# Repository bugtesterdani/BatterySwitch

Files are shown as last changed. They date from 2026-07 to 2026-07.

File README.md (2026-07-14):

# BatterySwitch – Automatischer 2-Akku-Umschalter (58–72 V, 40 A)

Automatische Umschaltung zwischen zwei Akkus (Batterie 1: 50 Ah, Batterie 2: 30 Ah)
in einem **72-V-System** (ca. 71,x V Ladeschluss, ca. 58 V Entladeschluss — z. B.
17s-Li-Ion oder 20s-LiFePO4) durch **direkten Vergleich der beiden Akkuspannungen**
(differentiell, keine feste Umschaltschwelle). Die Umschaltung erfolgt verschleißfrei
über Leistungs-MOSFETs (ausgelegt für ca. 40 A Dauerstrom). Beide Umschalt-Offsets
sind **über je ein Potentiometer getrennt einstellbar**.

## Funktionsprinzip

- Zustand **„Akku 1 aktiv“**: Auf Akku 2 wird umgeschaltet, sobald
  `U(Akku 1) < U(Akku 2) − Δ1` — Δ1 einstellbar mit Poti 1 (ca. 0,4 … 2,9 V).
- Zustand **„Akku 2 aktiv“**: Zurückgeschaltet wird, sobald
  `U(Akku 2) < U(Akku 1) − Δ2` — Δ2 einstellbar mit Poti 2 (unabhängig nachjustierbar).
- Zusätzlich wirkt eine **feste Zusatzhysterese** (ca. 0,1 … 0,8 V je Richtung,
  abhängig von den Poti-Stellungen). Das gesamte Umschaltfenster beträgt damit
  `Δ1 + Δ2` (typisch 2 … 4 V) — die Schaltung schaltet selten, und der
  Stützkondensator am Ausgang wird durch Umschalt-Totzeiten kaum belastet.
- Beim Leerfahren wechseln sich die Akkus automatisch ab und werden gemeinsam
  entladen; wird einer der Akkus geladen, übernimmt er automatisch die Last.

```
 BAT1 (50Ah, 72V) o──[Sicherung 50A/80VDC]──┤ MOSFET-Schalter S1 ├──┐
      │ Sense                                                        ├──o LAST +
 BAT2 (30Ah, 72V) o──[Sicherung 50A/80VDC]──┤ MOSFET-Schalter S2 ├──┘
      │ Sense                                          ▲
      ▼                                                │
  Differenzkomparator (U1 ⇄ U2) ───────────────────────┘
  Δ1-Poti · Δ2-Poti · Photovoltaik-Gate-Treiber · Break-before-make
```

## Eckdaten

| Parameter | Wert |
|---|---|
| Systemspannung | 58 … 72 V DC |
| Dauerstrom | 40 A (Spitze kurzzeitig höher) |
| Schaltelemente | antiserielle N-Kanal-MOSFETs je Zweig (IRF100P219, TO-247, 100 V, ≤ 2 mΩ) |
| Verlustleistung bei 40 A | ca. 7 W je Zweig (1 Paar) bzw. 3,5 W (2 Paare parallel, empfohlen) → Kühlkörper |
| Gate-Ansteuerung | Photovoltaik-Treiber VOM1271 (potentialfrei, inhärent break-before-make) |
| Umschaltkriterium | Differenz U1 − U2 (kein fester Spannungswert) |
| Δ1 (auf Akku 2 schalten) | Poti 1, ca. 0,4 … 2,9 V |
| Δ2 (auf Akku 1 zurück) | Poti 2, ca. 0,4 … 2,9 V |
| Zusatzhysterese (fest) | ca. 0,1 … 0,8 V je Richtung |
| Umschalt-Totzeit | 5 … 10 ms (Akkus werden nie parallel geschaltet) |
| Eigenverbrauch Steuerung | ca. 25 mA (≈ 1,8 W, ≈ 0,6 Ah/Tag) |

## Dokumentation

| Dokument | Inhalt |
|---|---|
| [hardware/BatterySwitch.kicad_sch](hardware/BatterySwitch.kicad_sch) | **KiCad-Schaltplan** (KiCad 6/7/8/9, direkt zu öffnen) — Vorschau: [hardware/preview.svg](hardware/preview.svg) |
| [hardware/BatterySwitch_Steuerplatine.kicad_pcb](hardware/BatterySwitch_Steuerplatine.kicad_pcb) | **Platinenlayout Steuerplatine** (112×92 mm, 2 Lagen, geroutet) — Vorschau: [hardware/preview_pcb.svg](hardware/preview_pcb.svg) |
| [docs/schaltung.md](docs/schaltung.md) | Vollständige Schaltungsbeschreibung, Schaltbilder, Dimensionierung und Formeln |
| [docs/stueckliste.md](docs/stueckliste.md) | Stückliste (BOM) mit Bauteilwerten und Alternativen |
| [docs/bestellliste.md](docs/bestellliste.md) | Bestellliste mit Händlern, Links und ca.-Preisen inkl. MwSt |
| [docs/aufbau-und-abgleich.md](docs/aufbau-und-abgleich.md) | Aufbauhinweise, Verkabelung, Nullabgleich und Einstellen von Δ1/Δ2 |

## Sicherheitshinweise

- **72 V DC ist keine Schutzkleinspannung.** Berührungsschutz vorsehen, nicht
  unter Spannung arbeiten, DC-Lichtbögen beim Trennen unter Last beachten.
- **Die Minusleitungen beider Akku-Stecker werden im Umschalter-Kabelbaum mit
  dem Fahrzeug-Minus verbunden** (gemeinsame Masse nur im Kabelbaum – an den
  Akkus wird nichts geändert, Einzelbetrieb ohne Board bleibt möglich).
  Geschaltet wird ausschließlich der Pluspfad (High-Side).
- Jeder Akku-Anschluss wird **direkt an der Anschlussklemme mit 50 A abgesichert** — Sicherungen mit
  **≥ 80 V DC-Zulassung** (z. B. gPV 14×51). Kfz-Sicherungen (MIDI/MEGA/ANL,
  32 V) sind ungeeignet. Die Sense-Leitungen separat mit 100 mA absichern.
- Leitungsquerschnitt für den Lastpfad: mindestens **10 mm²** bei 40 A. Die beiden
  Sense-Abgriffe direkt an den Anschlussklemmen der Akku-Stecker (vor F1/F2),
  jeweils mit 100 mA abgesichert; beide Akkuzuleitungen gleich ausführen.
- Während der Umschaltung ist die Last für 5 … 10 ms stromlos
  (Break-before-make). Motorcontroller mit eigenem Zwischenkreis stört das nicht.
- Die Schaltung vergleicht nur **relativ** — es gibt keinen absoluten
  Tiefentladeschutz. Die BMS der Akkus bleiben die letzte Schutzinstanz
  (siehe „Grenzen“ in der Schaltungsbeschreibung).

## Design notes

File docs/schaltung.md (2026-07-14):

# Schaltungsbeschreibung

**Systemspannung: 58 … 72 V** (Akkus mit ca. 71,x V Ladeschluss- und ca. 58 V
Entladeschlussspannung, z. B. 17s-Li-Ion oder 20s-LiFePO4).

Die Schaltung vergleicht die Spannungen **beider Akkus direkt miteinander**
(differentiell) – es gibt keine feste Umschaltspannung:

- Zustand **„Akku 1 aktiv“**: Umschalten auf Akku 2, sobald `U1 < U2 − Δ1`
- Zustand **„Akku 2 aktiv“**: Zurückschalten auf Akku 1, sobald `U2 < U1 − Δ2`

Δ1 und Δ2 werden mit **zwei getrennten Potis** eingestellt (je ca. 0,4 … 2,9 V).
Konstruktionsbedingt kommt eine **feste Zusatzhysterese** hinzu (ca. 0,1 … 0,8 V je
Richtung, siehe unten), sodass das Umschaltfenster nie kollabiert und die Schaltung
auch bei knapp eingestellten Potis nur selten schaltet.

> **Achtung – 72 V DC:** Spannungen über 60 V DC gelten nicht mehr als
> Schutzkleinspannung. Berührungsschutz vorsehen, isoliertes Werkzeug verwenden,
> niemals unter Spannung arbeiten. DC-Lichtbögen beim Trennen unter Last beachten.

Funktionsblöcke:

1. [Hilfsspannung VCC (12 V) aus 72 V](#1-hilfsspannung-vcc-12-v-aus-72-v)
2. [Messteiler mit Nullabgleich](#2-messteiler-mit-nullabgleich)
3. [Differenzkomparator mit zwei Hysterese-Potis](#3-differenzkomparator-mit-zwei-hysterese-potis)
4. [Gate-Ansteuerung mit Photovoltaik-Treibern](#4-gate-ansteuerung-mit-photovoltaik-treibern)
5. [Leistungsschalter](#5-leistungsschalter)

Bezeichner (R1, Q1, …) sind konsistent mit der [Stückliste](stueckliste.md).

---

## 1. Hilfsspannung VCC (12 V) aus 72 V

Der LM393 (max. 36 V) kann nicht direkt an 72 V betrieben werden. Ein einfacher
Längsregler aus Zener + Hochvolt-NPN erzeugt eine 12-V-Hilfsschiene. Versorgt wird
er über zwei Schottky-Dioden aus **beiden** Akkus (Dioden-OR), damit die Steuerung
weiterläuft, solange mindestens ein Akku Spannung liefert:

```
BAT1+ o────|>|──────┬──────────────────────┬────o  V+ (≈ max(U1,U2) − 0,4 V)
           D1       │                      │
BAT2+ o────|>|──────┤            [R19a 5,6k / 0,5 W]
           D2      ─┴─ C12               [R19b 5,6k / 0,5 W]
                   ─┬─ 100nF/100V          │
                    │                      ├──────B┤ T5 (MJE340, 300 V)
                    │                      │       │E
                    │                     ─┴─      ├────────o  VCC ≈ 12,3 V
                    │                  ZD3 ▲ 13V  ─┴─ C1 100 µF/25 V
                    │                     ─┬─     ─┬─  + C2 100 nF
GND   o─────────────┴──────────────────────┴──────┴─────────o  GND
                     (Minus beider Akku-Stecker im Kabelbaum verbunden)
```

- Zenerstrom: `(V+ − 13 V) / 11,2 kΩ ≈ 4 … 5 mA`
- T5 verheizt `(V+ − 12,3 V) · ILast ≈ 0,6 W` → TO-126 mit kleinem Aufsteckkühlkörper
- Gesamt-Eigenverbrauch der Schaltung (inkl. Messteiler, Status-LED und
  Optokoppler-LED): **ca. 25 mA aus 72 V ≈ 1,8 W** (≈ 0,6 Ah/Tag)

## 2. Messteiler mit Nullabgleich

Beide Akkuspannungen werden mit **identischen Teilern** (÷28) auf das
Eingangsspannungsniveau des Komparators gebracht. Der Sense-Abgriff (über flinke
100-mA-Sicherungen F3/F4 – eine gequetschte Sense-Leitung an 72 V ist sonst ein
Brandrisiko) erfolgt **direkt an der Anschlussklemme des Akku-Steckers im
Umschalter, vor der Hauptsicherung** – an die Batteriepole selbst kommt man bei
Steckakkus nicht heran, und das ist auch nicht nötig: Abfälle *hinter* dem
Abgriff (F1/F2, MOSFETs) gehen nicht in die Messung ein. Nur Akkukabel und
Steckerkontakt *vor* dem Abgriff wirken als kleiner Messfehler (~0,1–0,3 V bei
40 A, nur beim aktiven Akku) – gleiche Richtung wie der Lasteinbruch, also
unkritisch, solange beide Zuleitungen ähnlich ausgeführt sind:

```
BAT1+ (Sense) o──[F3]──[R1a 27k]──[R1b 27k]──┬─────o  Knoten A  (→ IN+)
                                            ─┴─ C3 100 nF
                                            ─┬─
                                             ├──[R2 2,0k]──o GND

BAT2+ (Sense) o──[F4]──[R3a 27k]──[R3b 27k]──┬─────o  Knoten B  (→ IN−)
                                            ─┴─ C4 100 nF
                                            ─┬─
                                             ├──[R4 1,8k]──[RV3 500Ω Trimmer]──o GND
```

- Teilerverhältnis `α = 2k / 56k ≈ 0,0357` → Knotenspannung ≈ 2,1 V (58 V) … 2,55 V (71,4 V);
  Innenwiderstand je Knoten `Rth = 54k ∥ 2k ≈ 1,93 kΩ`.
- Der obere Teilerwiderstand ist **aufgeteilt in 2× 27 kΩ** (Spannungs- und
  Verlustleistungsreserve; ≈ 35 V und 45 mW je Widerstand).
- **RV3 gleicht die Toleranzen der Teiler ab** (Nullabgleich). Bei ÷28-Teilung
  erzeugen schon 1-%-Widerstände bis zu ±1 V scheinbare Differenz auf
  Batterieebene – ohne Abgleich unbrauchbar. Prozedur siehe
  [Aufbau und Abgleich](aufbau-und-abgleich.md). R1–R4 als Metallfilm 1 %
  (besser 0,1 %), beide Teiler thermisch benachbart aufbauen (gleiche Drift).
- C3/C4 filtern Störspitzen. Nicht wesentlich vergrößern (max. ≈ 470 nF), sonst
  wird die Mitkopplung des Komparators zu träge.

## 3. Differenzkomparator mit zwei Hysterese-Potis

Kern der Schaltung ist ein LM393 (Dual-Komparator, Open-Collector), betrieben an
VCC = 12 V. **Komparator U1a** vergleicht Knoten A (Akku 1) mit Knoten B (Akku 2).
**Komparator U1b** arbeitet als Inverter und erzeugt das Gegensignal /OUT.

Die beiden Offsets Δ1 und Δ2 entstehen durch **zustandsabhängige Stromeinspeisung**
in die Messknoten: Poti RV1 speist von OUT in Knoten A, Poti RV2 speist von /OUT in
Knoten B. Es ist immer genau eine der beiden Einspeisungen aktiv (high):

```
                      VCC                           VCC
                        │                             │
                      [R7 3,3k]                     [R8 3,3k]
                        │                             │
 Knoten A o────┬────────┼────► OUT                    ├────► /OUT
               │      │\│      (high = Akku 1 aktiv)  │
               └──────│+ \                          │\│
                      │    ────┬────────────────────│− \
 Knoten B o───┬───────│− /     │                    │    ──────┬──► /OUT
              │       │/ U1a   │      VCC ──[R9 47k]│+ /       │
              │                │            ├───────│/ U1b     │
              │                │   [R10 47k]│ = VCC/2, C11 100n│
              │                │           GND                 │
              │                │                               │
              │                └──[JP1]──[R5 150k]──[RV1 1M]──┐│
 Knoten A o───┼───────────────────────────────────────────────┘│  (Δ1)
              │                                                 │
              └──────[JP2]──[R6 150k]──[RV2 1M]─────────────────┘  (Δ2)
```

*(JP1/JP2 sind Jumper, die nur für den Nullabgleich geöffnet werden.)*

### Funktionsweise

**Zustand „Akku 1 aktiv“ (OUT high, /OUT low):**
RV1 speist Strom von OUT (≈ VCC) in Knoten A → Akku 1 „wirkt“ um Δ1 höher.
Gleichzeitig zieht RV2 den Knoten B leicht Richtung /OUT (= 0 V) → kleiner fester
Zusatz. Der Komparator kippt erst, wenn

```
U1  <  U2 − Δ1        (Umschalten auf Akku 2)
```

**Zustand „Akku 2 aktiv“ (OUT low, /OUT high):**
Jetzt speist RV2 von /OUT in Knoten B → Akku 2 „wirkt“ um Δ2 höher, RV1 zieht
Knoten A leicht herunter. Zurückgeschaltet wird erst, wenn

```
U2  <  U1 − Δ2        (Zurückschalten auf Akku 1)
```

Das gesamte Umschaltfenster beträgt `Δ1 + Δ2` — nach jedem Umschalten muss sich das
Spannungsverhältnis der Akkus um mindestens dieses Fenster ändern, bevor wieder
geschaltet wird.

> **Wichtig bei 40 A:** Ein 72-V-Akku bricht unter 40 A Last je nach
> Innenwiderstand um 1 … 3 V ein. Damit die Schaltung nach dem Umschalten nicht
> sofort zurückpendelt (der entlastete Akku erholt sich, der neue bricht ein),
> muss `Δ1 + Δ2 > 2 × Lasteinbruch` sein. Deshalb reicht der Einstellbereich
> hier bis ca. 3 V je Richtung (Fenster bis ≈ 7 V).

### Dimensionierung

Einspeisung von OUT (High-Pegel ≈ VCC − 1 V ≈ 10,7 V, Knotenspannung ≈ 2,4 V) über
`Rf = R5 + RV-Anteil` in einen Knoten mit `Rth ≈ 1,93 kΩ`:

```
Δ (eigener Anteil)  ≈ (UOUT,high − UKnoten) · Rth / (Rth + Rf) / α
Δ (fester Zusatz)   ≈  UKnoten · Rth / (Rth + Rf,anderes Poti) / α
Δ1_eff = Δ1(RV1, eigener Anteil) + Zusatz(RV2)      (Δ2 analog mit vertauschten Rollen)
```

| Poti-Stellung | Rf | eigener Anteil | fester Zusatz fürs **andere** Δ |
|---|---|---|---|
| 0 Ω | 150 kΩ | ≈ 2,9 V | ≈ 0,84 V |
| 250 kΩ | 400 kΩ | ≈ 1,1 V | ≈ 0,32 V |
| 500 kΩ | 650 kΩ | ≈ 0,69 V | ≈ 0,20 V |
| 1 MΩ | 1,15 MΩ  | ≈ 0,39 V | ≈ 0,11 V |

**Einstellbereich je Richtung: ca. 0,4 … 2,9 V** (plus fester Zusatz).

Zwei bewusste Eigenschaften dieser einfachen Lösung (für den Einsatzzweck
unkritisch, da beide Potis ohnehin empirisch nachjustiert werden):

1. **Leichte gegenseitige Beeinflussung:** Jedes Poti trägt über den festen Zusatz
   ca. 10–25 % zum jeweils *anderen* Δ bei → beim Einstellen wechselseitig
   nachjustieren. Genau dieser Zusatz liefert die gewünschte feste Extra-Hysterese
   („nochmal ~0,5 V obendrauf“), damit nicht zu oft geschaltet wird.
2. **Δ skaliert schwach mit VCC**, die von der Zenerdiode stabilisiert wird –
   Restabhängigkeit von der Batteriespannung < 5 %.

### Inverter U1b

Der zweite LM393-Komparator vergleicht OUT mit VCC/2 (R9/R10 = 47 kΩ, C11 100 nF)
und liefert /OUT mit sauberem Pegel (Pull-up R8). /OUT steuert die Einspeisung von
Δ2, den Gate-Treiber von Schalter 1 und die LED „Akku 2 aktiv“.

### Verhalten beim Einschalten

Liegen beide Akkuspannungen beim Einschalten innerhalb des Fensters
(|U1 − U2| < Δ), ist der Anfangszustand nicht definiert – die Schaltung wählt
einen Akku und bleibt dort stabil. Das ist unkritisch.

## 4. Gate-Ansteuerung mit Photovoltaik-Treibern

Die N-Kanal-MOSFETs schalten high-side: Ihre Gates müssen ca. 8 … 10 V **über der
72-V-Schiene** liegen (≈ 80 V gegen Masse). Statt einer Hochvolt-Ladungspumpe
kommen **Photovoltaik-MOSFET-Treiber (VOM1271)** zum Einsatz: Eine interne
LED beleuchtet einen Fotodioden-Stapel, der potentialfrei ca. 8,4 V direkt
zwischen Gate und Source liefert – egal, auf welchem Potential die Source liegt.

```
                                  ┌────────────────────┐
V+ ──[R17a 3,3k/1W]──[R17b 3,3k/1W]──|>|── LED         │ OC1 (VOM1271)
                                  │   intern           │
             MPSA42 (300 V!)  C┤──┘        + o─────────┼───o Gate1  (Q1/Q2)
/OUT? nein: OUT-Logik s.u.  B─┤ T1                     │
   OUT o──[R11 27k]───────────┤        − o─────────────┼───o Source-Knoten Q1/Q2
                              │E       (integrierte    │
                             GND        Schnellent-    │
                                        ladung)        │
                                  └────────────────────┘
   (identisch: T2 + R12 27k + R18a/b + OC2 → Gate2/Source-Knoten Q3/Q4,
    T2-Basis an /OUT)
```

- **T1 (Basis an OUT)** schaltet OC1 → Akku-1-Zweig, **T2 (Basis an /OUT)**
  schaltet OC2 → Akku-2-Zweig. Es leuchtet immer nur eine Treiber-LED.
- T1/T2 sind **MPSA42 (300 V)**: Im ausgeschalteten Zustand liegt der Kollektor
  über die LED-Vorwiderstände an V+ (72 V) – ein BC547 (45 V) würde sterben.
- LED-Strom: `(V+ − 1,3 V) / 6,6 kΩ ≈ 9 … 11 mA` über den gesamten
  Batteriespannungsbereich.

### Break-before-make – hier gratis

- **Einschalten langsam:** Der Fotodioden-Stapel liefert nur ~10 µA. Mit der
  Gate-Kapazität der MOSFETs (2× ≈ 10 nF) dauert das Aufladen bis zur
  Schwellspannung **5 … 10 ms** – die Umschaltung ist ein sanfter Soft-Start.
- **Ausschalten schnell:** Der VOM1271 enthält eine aktive
  Schnellentladeschaltung, die das Gate in **< 1 ms** entlädt.

Beim Umschalten (beide LEDs wechseln gleichzeitig) ist der alte Zweig also längst
gesperrt, bevor der neue zu leiten beginnt → **die Akkus werden nie parallel
geschaltet** (wichtig, da sie beim Umschalten konstruktionsbedingt Δ Volt
Differenz haben und sonst hohe Ausgleichsströme flössen).

Während der Totzeit (5 … 10 ms) ist die Last stromlos. Der Stützkondensator C8
überbrückt das nur für kleine Steuerlasten – ein Motorcontroller als Hauptlast
hat aber selbst genug Zwischenkreiskapazität und übersteht die Lücke problemlos.
Da das Umschaltfenster Δ1 + Δ2 groß ist, tritt die Totzeit ohnehin nur selten auf.

## 5. Leistungsschalter

### Antiserielle MOSFET-Paare

Jeder Batteriezweig besteht aus **zwei antiseriellen N-Kanal-MOSFETs**
(Source an Source, Gates verbunden). Nur so sperrt der Schalter in **beide**
Richtungen – mit einem einzelnen MOSFET würde dessen Body-Diode die inaktive
Batterie weiter mit der Last (bzw. mit der anderen Batterie) verbinden.

```
                 Q1 (IRF100P219)    Q2 (IRF100P219)
BAT1+ o──[F1]────D─┤├─S────────S─┤├─D──────────────┬─────o LAST+
                     │►(Body)  ◄│                  │
                     └────┬─────┘                  │
              Gate1 ──────┤   ZD1 15 V             │
              (von OC1)   └──▲├── Source-Knoten    │
                                                   │
                 Q3 (IRF100P219)    Q4 (IRF100P219)│
BAT2+ o──[F2]────D─┤├─S────────S─┤├─D──────────────┘
                     │►        ◄│                 ─┴─ C8  2× 470 µF/100 V
                     └────┬─────┘                 ─┬─  (Stützkondensator)
              Gate2 ──────┤   ZD2 15 V             │
              (von OC2)   └──▲├── Source-Knoten   GND
```

- **MOSFET-Anforderungen:** `UDS ≥ 100 V` (71,4 V max. + Reserve für
  Schaltspitzen), `RDS(on) ≤ 3 mΩ`, gut durchgesteuert bei UGS = 8 V
  (der VOM1271 liefert ca. 8,4 V). Referenztyp IRF100P219 (TO-247, 100 V, ≤ 2 mΩ);
  Alternative IPP023N10N5.
- **Verlustleistung bei 40 A:** `P = 40² · 2 · ≈2,2 mΩ ≈ 7 W` je aktivem Zweig
  (bei UGS 8 V etwas über Datenblattwert) → **dringend empfohlen: je Zweig zwei
  Paare parallel** (8 MOSFETs gesamt, je 10 Ω Einzelgate-Widerstand gegen
  Schwingen) → ≈ 3,5 W je Zweig, ca. 0,9 W pro Gehäuse. Kühlkörper ≤ 6 K/W.
- ZD1/ZD2 (15 V, Gate–Source) schützen die Gates vor eingekoppelten Transienten.
- **Verdrahtungsinduktivität klein halten** (kurze, dicke Leitungen): Beim
  Abschalten unter 40 A erzeugt jede µH Leitungsinduktivität Spannungsspitzen,
  die die 100-V-Reserve aufbrauchen. Bei langen Batterieleitungen je Akku einen
  Elko (220 µF/100 V) direkt an den Schalter-Eingang setzen.

### Status-LEDs

Die LEDs hängen an VCC und werden über eigene Transistoren getrieben, damit sie
die Pegel von OUT//OUT (Einspeisequellen für Δ1/Δ2!) nicht verfälschen:

```
VCC ──[R15 2,2k]──|>|──C┤ T3 (BC547)   Basis ← OUT  via R13 330k
      LED1 grün         │E             „Akku 1 aktiv“
                       GND
VCC ──[R16 2,2k]──|>|──C┤ T4 (BC547)   Basis ← /OUT via R14 330k
      LED2 gelb         │E             „Akku 2 aktiv“
                       GND
```

---

## Grenzen und mögliche Erweiterungen

- **Kein absoluter Tiefentladeschutz:** Die Schaltung vergleicht nur *relativ*.
  Beim Leerfahren wechseln sich die Akkus ab („Leapfrog“) und werden gemeinsam
  entladen – gewollt, um beide Kapazitäten zu nutzen. Die **BMS der beiden Akkus
  bleiben die letzte Instanz** gegen Tiefentladung; bei Akkus ohne BMS einen
  externen Low-Voltage-Disconnect hinter den Ausgang schalten.
- **Kein Laderegler:** Die Schaltung verteilt nur die Entladung. Das Laden beider
  Akkus muss separat erfolgen. Wird ein Akku geladen, während der andere entladen
  ist, schaltet die Last automatisch auf den geladenen Akku – gewolltes Verhalten
  des Differenzvergleichs.
- **Verpolschutz:** Nicht enthalten – bei Verpolung eines Akkus leiten die
  Body-Dioden. Sicherungen F1/F2 begrenzen den Schaden; sorgfältig anschließen.
- **Fehlerfall Messteiler:** Reißt ein unterer Teilerwiderstand (R2/R4) ab, liegt
  der volle Akku an einem LM393-Eingang (max. 36 V) – der Komparator stirbt und
  der Zustand ist undefiniert. Wer es robust mag, ergänzt je Knoten eine
  10-V-Zener nach Masse (identisch an beiden Knoten, um die Symmetrie zu wahren).

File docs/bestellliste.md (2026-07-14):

# Bestellliste

> **Stand: Juli 2026.** Die Händler-Shops blockieren automatische Preisabfragen,
> daher sind die Preise **ca.-Angaben inkl. 19 % MwSt** (aus aktuellen
> Katalogpreisen abgeleitet) — beim Klick auf den Link bitte den Tagespreis
> prüfen. Mengen entsprechen der [Stückliste](stueckliste.md) inkl. der
> empfohlenen 8 MOSFETs (2 Paare parallel je Zweig).

## 1. Mouser (mouser.de) — Halbleiter, die Reichelt nicht führt

Mouser zeigt Preise netto an, an der Kasse kommt MwSt dazu. Versand kostenlos ab 50 € netto, sonst ca. 20 € → **zusammen mit den MOSFETs bestellen, dann ist die Grenze erreicht.**

| Pos. | Bauteil | Menge | Link | ca. €/Stk inkl. MwSt | Summe |
|---|---|---|---|---|---|
| Q1–Q8 | IRF100P219 (TO-247, 100 V, ≤ 2 mΩ) | 8 | [mouser.de/c/?q=IRF100P219](https://www.mouser.de/c/?q=IRF100P219) | 4,50 € | 36,00 € |
| OC1, OC2 | VOM1271T (Vishay, SOP-4) | 2 | [mouser.de → VOM1271T](https://www.mouser.de/ProductDetail/Vishay-Semiconductors/VOM1271T) | 2,90 € | 5,80 € |
| – | SOP-4→DIP-Adapterplatinen (bei Lochraster-Aufbau) | 2 | [mouser.de/c/?q=SOP-4+adapter](https://www.mouser.de/c/?q=SOIC-4+adapter) | 1,00 € | 2,00 € |

**Zwischensumme Mouser: ca. 44 €** *(alternativ DigiKey [digikey.de](https://www.digikey.de), gleiche Teile, ähnliche Preise)*

## 2. Reichelt (reichelt.de) — Standard-Bauteile

Links führen auf die Reichelt-Suche mit dem passenden Suchbegriff. Versand ca. 5,95 €.

| Pos. | Bauteil | Menge | Reichelt-Suche | ca. €/Stk inkl. MwSt | Summe |
|---|---|---|---|---|---|
| U1 | LM393 DIP-8 | 1 | [LM 393 DIP](https://www.reichelt.de/index.html?ACTION=446&q=LM%20393%20DIP) | 0,25 € | 0,25 € |
| T1, T2 | MPSA42 (300 V) | 2 | [MPSA 42](https://www.reichelt.de/index.html?ACTION=446&q=MPSA%2042) | 0,12 € | 0,24 € |
| T3, T4 | BC547B | 2 | [BC 547B](https://www.reichelt.de/index.html?ACTION=446&q=BC%20547B) | 0,06 € | 0,12 € |
| T5 | MJE340 (TO-126) | 1 | [MJE 340](https://www.reichelt.de/index.html?ACTION=446&q=MJE%20340) | 0,55 € | 0,55 € |
| D1, D2 | 1N5819 | 2 | [1N 5819](https://www.reichelt.de/index.html?ACTION=446&q=1N%205819) | 0,10 € | 0,20 € |
| ZD1, ZD2 | Zener 15 V 0,5 W (BZX55C15) | 2 | [ZF 15](https://www.reichelt.de/index.html?ACTION=446&q=ZF%2015) | 0,10 € | 0,20 € |
| ZD3 | Zener 13 V 1,3 W (BZX85C13) | 1 | [ZD 13](https://www.reichelt.de/index.html?ACTION=446&q=ZD%2013) | 0,20 € | 0,20 € |
| LED1, LED2 | LED 3 mm grün + gelb | 2 | [LED 3mm](https://www.reichelt.de/index.html?ACTION=446&q=LED%203mm%20gruen) | 0,15 € | 0,30 € |
| R1–R4 | Metallfilm 1 %: 4× 27 kΩ, 1× 2,0 kΩ, 1× 1,8 kΩ | 6 | [METALL 27,0K](https://www.reichelt.de/index.html?ACTION=446&q=METALL%2027%2C0K) usw. | 0,10 € | 0,60 € |
| R5–R16 | Metallfilm: 2× 150 k, 2× 3,3 k, 2× 47 k, 2× 27 k, 2× 330 k, 2× 2,2 k | 12 | [METALL …](https://www.reichelt.de/index.html?ACTION=446&q=METALL%20150K) | 0,10 € | 1,20 € |
| R17, R18 | Metalloxid 3,3 kΩ 1 W (oder 2 W) | 4 | [2W METALL 3,3K](https://www.reichelt.de/index.html?ACTION=446&q=2W%20METALL%203%2C3K) | 0,20 € | 0,80 € |
| R19 | 5,6 kΩ 0,5 W | 2 | [1/2W 5,6K](https://www.reichelt.de/index.html?ACTION=446&q=1%2F2W%205%2C6K) | 0,10 € | 0,20 € |
| Rg | 10 Ω (Einzelgate-Widerstände) | 8 | [METALL 10,0](https://www.reichelt.de/index.html?ACTION=446&q=METALL%2010%2C0) | 0,10 € | 0,80 € |
| RV1, RV2 | Poti 1 MΩ linear, 6-mm-Achse | 2 | [PO4M-LIN 1,0M](https://www.reichelt.de/index.html?ACTION=446&q=PO4M-LIN%201%2C0M) | 1,50 € | 3,00 € |
| RV3 | Spindeltrimmer 500 Ω, 25 Gang | 1 | [64W-500](https://www.reichelt.de/index.html?ACTION=446&q=64W-500) | 1,80 € | 1,80 € |
| C2–C4, C11 | 100 nF Keramik X7R | 5 | [X7R-2,5 100N](https://www.reichelt.de/index.html?ACTION=446&q=X7R-2%2C5%20100N) | 0,08 € | 0,40 € |
| C12 | 100 nF / 100 V Keramik | 1 | [X7R-5 100N](https://www.reichelt.de/index.html?ACTION=446&q=X7R-5%20100N) | 0,15 € | 0,15 € |
| C1 | Elko 100 µF / 25 V | 1 | [RAD 100/25](https://www.reichelt.de/index.html?ACTION=446&q=RAD%20100%2F25) | 0,10 € | 0,10 € |
| C8 | Elko low-ESR 470 µF / 100 V (z. B. Panasonic FC/FR) | 2 | [Elko 470µ 100V](https://www.reichelt.de/index.html?ACTION=446&q=470%C2%B5F%20100V%20low%20esr) | 1,90 € | 3,80 € |
| optional | Elko 220 µF / 100 V (Eingangs-Snubber) | 2 | [220µ 100V](https://www.reichelt.de/index.html?ACTION=446&q=220%C2%B5F%20100V) | 1,20 € | 2,40 € |
| KK1 | Kühlkörper ≤ 3 K/W (z. B. Fischer SK-Profil, 75–100 mm) | 1 | [Kühlkörper SK](https://www.reichelt.de/index.html?ACTION=446&q=K%C3%BChlk%C3%B6rper%20SK%20100) | 5,50 € | 5,50 € |
| KK2 | Aufsteckkühlkörper TO-126 | 1 | [KK TO126](https://www.reichelt.de/index.html?ACTION=446&q=K%C3%BChlk%C3%B6rper%20TO-126) | 0,60 € | 0,60 € |
| – | Isoliermaterial TO-247 (Silikonscheiben + Buchsen) | 8 | [Glimmerscheibe TO-247](https://www.reichelt.de/index.html?ACTION=446&q=Isolierscheibe%20TO-247) | 0,30 € | 2,40 € |
| F3, F4 | Feinsicherung 100 mA flink 5×20 + Printhalter | 2+2 | [FLINK 0,1A](https://www.reichelt.de/index.html?ACTION=446&q=FLINK%200%2C1A) / [PL 112000](https://www.reichelt.de/index.html?ACTION=446&q=Sicherungshalter%205x20%20Print) | 0,55 € | 1,10 € |
| JP1, JP2 | Stiftleiste 2-polig + Jumper | 1+2 | [Stiftleiste 2,54](https://www.reichelt.de/index.html?ACTION=446&q=Stiftleiste%202%2C54) | 0,40 € | 0,40 € |
| – | Lochrasterplatine (Punktraster, ca. 100×100) | 1 | [H25PR100](https://www.reichelt.de/index.html?ACTION=446&q=H25PR100) | 1,60 € | 1,60 € |

**Zwischensumme Reichelt: ca. 28 € + 5,95 € Versand**

## 3. PV-/Solar-Händler — Sicherungen mit DC-Zulassung

Kfz-Sicherungen sind bei 72 V DC tabu; gPV-Sicherungen (Solartechnik) sind die
günstigste Quelle für DC-taugliche 50-A-Sicherungen. Gut zu finden bei
Solar-Shops, eBay oder Amazon:

| Pos. | Bauteil | Menge | Bezugsquelle | ca. €/Stk inkl. MwSt | Summe |
|---|---|---|---|---|---|
| F1, F2 | gPV-Sicherung 14×51 mm, 50 A, 1000 V DC (z. B. DF Electric, Mersen HP10M) | 2 | [eBay-Suche „gPV 14x51 50A“](https://www.ebay.de/sch/i.html?_nkw=gPV+Sicherung+14x51+50A) / [DF Electric](https://www.dfelectric.es/products/cylindrical-gpv-fuse-links/14x51-cylindrical-gpv-fuse-link/) | 6,00 € | 12,00 € |
| – | Sicherungshalter 14×51, 1000 V DC (z. B. DF PMX, Mersen) | 2 | [eBay-Suche „Sicherungshalter 14x51 PV“](https://www.ebay.de/sch/i.html?_nkw=Sicherungshalter+14x51+1000V+DC) | 8,00 € | 16,00 € |

**Zwischensumme Sicherungen: ca. 28 €**

## 4. Grandado — Super-Soco-Steckverbinder (deine Links)

| Pos. | Bauteil | Menge | Link | Preis |
|---|---|---|---|---|
| X3 | Batterieanschluss (Fahrzeugseite) | 1 | [grandado.com – Batterie-Stecker Super Soco](https://deu.grandado.com/products/n69r-fur-super-soco-lithium-batterie-stecker-ladegerat-buchse-linie-kreisformige-linie-fur-super-soco-tc-ts-tsx-cu-fur-super-soco-l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) | laut Shop |
| X1, X2 | Gegenstecker (Akkuseite) | 2 | [grandado.com – Gegenstecker Super Soco](https://deu.grandado.com/products/fit-super-soco-lithium-batterie-stecker-ladegerat-buchse-linie-rund-linie-quadratische-linie-fur-super-soco-tc-ts-tsx-cu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) | laut Shop |

*(Die Grandado-Produktseiten sind automatisiert nicht abrufbar — Preis bitte
direkt im Shop prüfen. Lieferzeit bei Grandado oft mehrere Wochen aus Fernost
einplanen. **Wichtig:** Strombelastbarkeit der Kontakte für 40 A Dauer prüfen,
Kontakte ggf. verlöten.)*

## 5. Baumarkt / Kfz-Bedarf

| Pos. | Bauteil | Menge | ca. Preis |
|---|---|---|---|
| – | Leitung 10 mm² rot/schwarz (Lastpfad) | 2 m | 6,00 € |
| – | Leitung 0,5 mm² (Sense) | 2 m | 1,00 € |
| – | Ringkabelschuhe M6/M8 10 mm², Schrumpfschlauch | Set | 5,00 € |
| – | Kleingehäuse/Montageplatte, Kabelverschraubungen | 1 | 8,00 € |

**Zwischensumme: ca. 20 €**

---

## Gesamtübersicht

| Block | ca. Summe inkl. MwSt |
|---|---|
| Mouser (MOSFETs, VOM1271) | 44 € |
| Reichelt (Standard-Bauteile) | 28 € + 5,95 € Versand |
| gPV-Sicherungen + Halter | 28 € |
| Super-Soco-Stecker (Grandado) | laut Shop |
| Baumarkt/Kfz | 20 € |
| **Gesamt (ohne Stecker)** | **≈ 125 … 135 €** |

### Spar-Optionen

- **Nur 4 statt 8 MOSFETs** (ein Paar je Zweig): −18 €, dafür ~7 W statt 3,5 W
  Abwärme → größerer Kühlkörper nötig.
- **NH00-Sicherungen** (50 A, bis 120 V DC je nach Typ) sind mit Halter oft
  günstiger als gPV aus dem Solar-Shop — dafür klobiger.
- Widerstände/Kondensatoren im Sortiment kaufen, falls noch kein Lager da ist.

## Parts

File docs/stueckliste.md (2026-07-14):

# Stückliste (BOM)

Bezeichner entsprechen der [Schaltungsbeschreibung](schaltung.md).
Auslegung für **58 … 72 V Systemspannung, 40 A Dauerstrom**.

## Halbleiter

| Bezeichner | Bauteil | Wert / Typ | Anmerkung |
|---|---|---|---|
| Q1–Q4 | N-Kanal-MOSFET | **IRF100P219** (TO-247, 100 V, ≤ 2 mΩ) | Alternative: IPP023N10N5. Anforderung: UDS ≥ 100 V, RDS(on) ≤ 3 mΩ, gut leitend bei UGS = 8 V. **Empfehlung: 8 Stück** (je Zweig zwei Paare parallel, halbiert die Verluste) |
| OC1, OC2 | Photovoltaik-Gate-Treiber | **VOM1271T** (SOP-4) | liefert potentialfrei ≈ 8,4 V Gate-Spannung, integrierte Schnellentladung. Alternativen: APV1122, TLP3906 (ohne Schnellentladung → externe Entladeschaltung nötig) |
| U1 | Komparator | **LM393** (DIP-8) | beide Hälften belegt: U1a Differenzkomparator, U1b Inverter; läuft an VCC = 12 V |
| T1, T2 | NPN-Transistor | **MPSA42** (TO-92, 300 V) | schalten die Treiber-LEDs; Kollektor liegt sperrend an V+ ≈ 72 V → kein BC547! |
| T3, T4 | NPN-Transistor | **BC547B** (TO-92) | LED-Treiber Status-LEDs (nur an VCC) |
| T5 | NPN-Transistor | **MJE340** (TO-126, 300 V) | Längsregler VCC; kleiner Aufsteckkühlkörper |
| D1, D2 | Schottky-Diode | **1N5819** (1 A / 40 V) | Dioden-OR der Versorgung (sehen max. ±14 V Differenz) |
| ZD1, ZD2 | Zener-Diode | **BZX55C15** (15 V, 0,5 W) | Gate-Schutz, direkt Gate–Source-Knoten |
| ZD3 | Zener-Diode | **BZX85C13** (13 V, 1,3 W) | Referenz des VCC-Reglers |
| LED1 | LED grün, 3 mm | – | „Akku 1 aktiv“ |
| LED2 | LED gelb, 3 mm | – | „Akku 2 aktiv“ |

## Widerstände (0,25 W Metallfilm, sofern nicht anders angegeben; R1–R4 unbedingt 1 %, besser 0,1 %)

| Bezeichner | Wert | Funktion |
|---|---|---|
| R1a, R1b | 27 kΩ, 1 % | Messteiler Akku 1, oben (2 in Serie wegen Spannung/Verlustleistung) |
| R2 | 2,0 kΩ, 1 % | Messteiler Akku 1, unten |
| R3a, R3b | 27 kΩ, 1 % | Messteiler Akku 2, oben |
| R4 | 1,8 kΩ, 1 % | Messteiler Akku 2, unten (fester Anteil, Rest über RV3) |
| R5, R6 | 150 kΩ | Serienwiderstände zu RV1/RV2 (begrenzen max. Δ auf ≈ 2,9 V) |
| R7, R8 | 3,3 kΩ | Pull-ups OUT und /OUT |
| R9, R10 | 47 kΩ | VCC/2-Teiler für Inverter U1b |
| R11, R12 | 27 kΩ | Basiswiderstände T1/T2 (MPSA42 braucht kräftige Basisansteuerung) |
| R13, R14 | 330 kΩ | Basiswiderstände T3/T4 (Status-LEDs) |
| R15, R16 | 2,2 kΩ | Vorwiderstände Status-LEDs |
| R17a, R17b | 3,3 kΩ, **1 W** (Metalloxid) | Vorwiderstand Treiber-LED OC1 (2 in Serie, von V+ ≈ 72 V) |
| R18a, R18b | 3,3 kΩ, **1 W** (Metalloxid) | Vorwiderstand Treiber-LED OC2 |
| R19a, R19b | 5,6 kΩ, 0,5 W | Zener-Vorwiderstand VCC-Regler (2 in Serie) |
| Rg (8×) | 10 Ω | Einzelgate-Widerstände, nur bei parallelen MOSFET-Paaren |

## Potentiometer / Trimmer

| Bezeichner | Wert | Funktion |
|---|---|---|
| RV1 | 1 MΩ Poti, linear (Frontplatte) | **Δ1**: Umschalten auf Akku 2 bei U1 < U2 − Δ1 (≈ 0,4 … 2,9 V) |
| RV2 | 1 MΩ Poti, linear (Frontplatte) | **Δ2**: Zurückschalten auf Akku 1 bei U2 < U1 − Δ2 (≈ 0,4 … 2,9 V) |
| RV3 | 500 Ω Trimmer, 25 Gang | **Nullabgleich** der beiden Messteiler |

## Kondensatoren

| Bezeichner | Wert | Funktion |
|---|---|---|
| C1 | 100 µF / 25 V Elko | Puffer VCC |
| C2 | 100 nF Keramik | Abblockung LM393 (direkt am IC) |
| C3, C4 | 100 nF Keramik | Filter an den Messknoten A und B (nicht > 470 nF!) |
| C8 | 2× 470 µF / **100 V** Low-ESR-Elko | Stützkondensator Lastausgang |
| C11 | 100 nF Keramik | Stützung VCC/2-Teiler |
| C12 | 100 nF / **100 V** Keramik/Folie | Abblockung V+ |
| (optional) | 220 µF / 100 V je Akku-Eingang | bei langen Batterieleitungen gegen Abschalt-Spannungsspitzen |

## Sonstiges

| Bezeichner | Bauteil | Anmerkung |
|---|---|---|
| X1, X2 | Super-Soco-Gegenstecker (Akku-Seite), 2× | Anschluss der beiden Akkus an den Umschalter |
| X3 | Super-Soco-Batteriestecker (Fahrzeug-Seite), 1× | Ausgang des Umschalters zum Fahrzeug/Controller. **Strombelastbarkeit der Stecker für 40 A Dauer prüfen** – Kontakte ggf. verlöten statt crimpen |
| JP1, JP2 | Jumper / Stiftleiste 2-polig | trennen die Δ-Einspeisungen für den Nullabgleich |
| F1, F2 | Sicherung 50 A, **≥ 80 V DC** | z. B. gPV 14×51 mm oder NH00 mit Halter. **Kfz-Sicherungen (MIDI/MEGA/ANL) sind nur bis 32 V zugelassen – ungeeignet!** So nah wie möglich an der Anschlussklemme des jeweiligen Akku-Steckers |
| F3, F4 | Feinsicherung 100 mA flink + Halter | in den beiden Sense-Leitungen, direkt an der Anschlussklemme des Akku-Steckers |
| KK1 | Kühlkörper ≤ 6 K/W | für die MOSFETs gemeinsam; elektrisch isoliert montieren (Drain = Kühlfahne!) |
| KK2 | Aufsteckkühlkörper TO-126 | für T5 (MJE340) |
| – | Leitung 10 mm² | gesamter Lastpfad (BAT+ → Schalter → Last, sowie Masseverbund) |
| – | Leitung 0,5 mm², 2× | Sense-Leitungen von den Anschlussklemmen der Akku-Stecker (vor F1/F2) zur Steuerplatine |
| – | M8/M6-Ringkabelschuhe, Schraubklemmen ≥ 40 A | Leistungsanschlüsse |

## Hinweise zur Beschaffung

- Die MOSFETs sind die einzigen „kritischen“ Bauteile. Bei 40 A Dauerstrom
  lieber ein moderneres/niederohmigeres Modell wählen als sparen — jedes mΩ sind
  1,6 W Abwärme. 100-V-Typen unter 2,5 mΩ sind gut verfügbar (TO-220/TO-247).
- VOM1271 gibt es nur in SMD (SOP-4) – auf eine kleine Adapterplatine löten,
  wenn auf Lochraster gebaut wird.
- RV1/RV2 als lineare Potis wählen (kein log!), sonst ist die Δ-Skala stark verzerrt.
- Alle Bauteile im Pfad V+ (R17/R18/R19, C12, T1/T2-Kollektoren, T5) sehen bis zu
  72 V — Spannungsfestigkeit beim Ersatztypen-Kauf beachten.

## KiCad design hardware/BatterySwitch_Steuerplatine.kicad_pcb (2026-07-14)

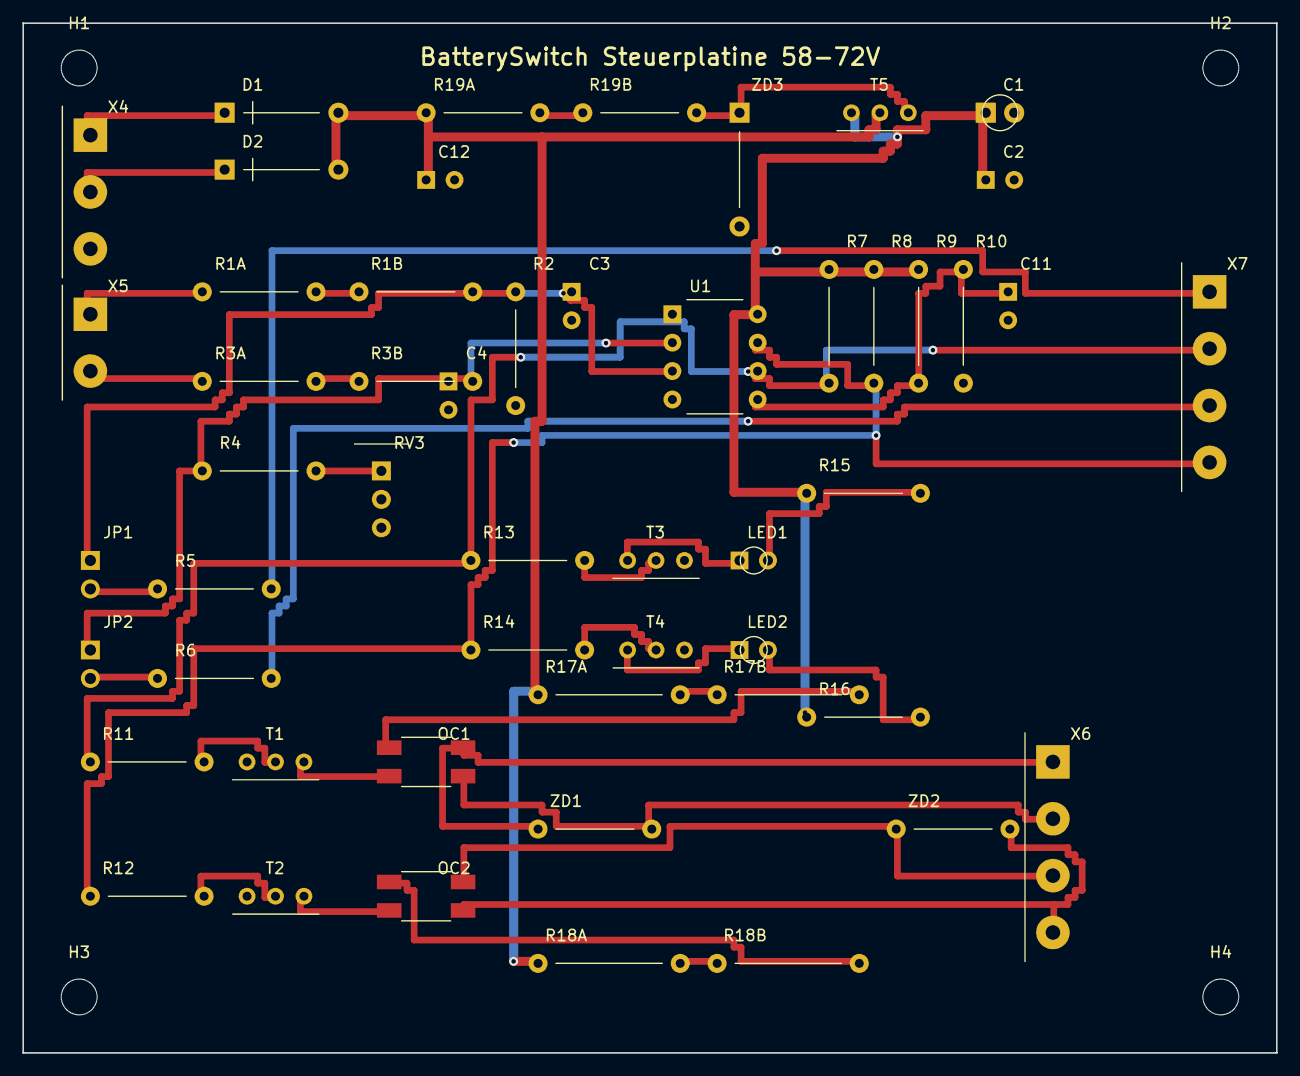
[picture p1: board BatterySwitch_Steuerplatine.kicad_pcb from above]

Board: 2 copper layers, 112.0 x 92.0 mm, 56 parts (0 on the bottom side), 39 nets.

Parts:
C1: 100u/25V; ELKO
C2: 100n; RAD
C3, C4, C11: 100n; RADV
C12: 100n/100V; RAD
D1, D2: 1N5819; DO41_AK
H1, H2, H3, H4: M3; MH32
JP1: Abgleich D1; HDR2
JP2: Abgleich D2; HDR2
LED1: gruen; LED3
LED2: gelb; LED3
OC1, OC2: VOM1271; SOP4
R1A, R1B, R3A, R3B: 27k 1%; AXH
R2: 2k0 1%; AXV
R4: 1k8 1%; AXH
R5, R6: 150k; AXH
R7, R8: 3k3; AXV
R9, R10: 47k; AXV
R11, R12: 27k; AXH
R13, R14: 330k; AXH
R15, R16: 2k2; AXH
R17A, R17B, R18A, R18B: 3k3/1W; AXH1W
R19A, R19B: 5k6/0,5W; AXH
RV3: 500R 25G; TRIM
T1, T2: MPSA42; TO92_EBC
T3, T4: BC547B; TO92_CBE
T5: MJE340; TO126_ECB
U1: LM393; DIP8
X4: V+ Eingaenge: B1F B2F GND; TERM3
X5: Sense: S1 S2; TERM2
X6: Gates: G1 SK1 G2 SK2; TERM4
X7: Potis: NJ2 OUT NK2 NOUT; TERM4
ZD1, ZD2: 15V; AXH
ZD3: 13V; DO41V

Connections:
A1: OC1.1, R17B.2
A2: OC2.1, R18B.2
B1F: D1.2, X4.1
B2F: D2.2, X4.2
G1: OC1.4, X6.1, ZD1.1
G2: OC2.4, X6.3, ZD2.1
GND: C1.2, C2.2, C3.2, C4.2, C11.2, C12.2, R2.2, R10.2, RV3.2, RV3.3, T1.3, T2.3, T3.3, T4.3, U1.4, X4.3, ZD3.2
K1: OC1.2, T1.2
K2: OC2.2, T2.2
KA: C3.1, JP1.1, R1B.2, R2.1, U1.3
KB: C4.1, JP2.1, R3B.2, R4.1, U1.2
LED1A: LED1.2, R15.2
LED1K: LED1.1, T3.2
LED2A: LED2.2, R16.2
LED2K: LED2.1, T4.2
N1A: R1A.2, R1B.1
N3A: R3A.2, R3B.1
N17: R17A.2, R17B.1
N18: R18A.2, R18B.1
N19: R19A.2, R19B.1
NJ1: JP1.2, R5.1
NJ2: R5.2, X7.1
NK1: JP2.2, R6.1
NK2: R6.2, X7.3
NOUT: R8.2, R12.1, R14.1, U1.7, X7.4
OUT: R7.2, R11.1, R13.1, U1.1, U1.6, X7.2
RVT: R4.2, RV3.1
S1: R1A.1, X5.1
S2: R3A.1, X5.2
SK1: OC1.3, X6.2, ZD1.2
SK2: OC2.3, X6.4, ZD2.2
T1B: R11.2, T1.1
T2B: R12.2, T2.1
T3B: R13.2, T3.1
T4B: R14.2, T4.1
V+: C12.1, D1.1, D2.1, R17A.1, R18A.1, R19A.1, T5.2
VCC: C1.1, C2.1, R7.1, R8.1, R9.1, R15.1, R16.1, T5.3, U1.8
VM: C11.1, R9.2, R10.1, U1.5
ZDK: R19B.2, T5.1, ZD3.1

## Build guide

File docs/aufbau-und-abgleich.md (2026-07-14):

# Aufbau und Abgleich

> **Sicherheit zuerst:** 72 V DC ist keine Schutzkleinspannung mehr. Nicht unter
> Spannung arbeiten, isoliertes Werkzeug, Berührungsschutz für alle blanken
> Leistungsanschlüsse. Beim Trennen unter Last entstehen DC-Lichtbögen –
> Verbindungen nur stromlos stecken/schrauben.

## 1. Mechanischer Aufbau

- **Leistungsteil** (Q1–Q4 bzw. Q1–Q8, F1/F2, C8) mit kurzen, dicken Leiterbahnen
  bzw. 10-mm²-Verdrahtung aufbauen. Bei Lochraster: Leistungsstrecke **nicht**
  über Lötaugen führen, sondern massive Drähte/Kupferschienen direkt an die
  MOSFET-Beine löten.
- MOSFETs auf gemeinsamen Kühlkörper montieren. **Achtung:** Die Kühlfahne des
  TO-247 ist Drain – Glimmerscheibe/Silikonpad + Isolierbuchse verwenden. Der
  Kühlkörper führt sonst 72 V bzw. schließt BAT1, BAT2 und Last kurz.
- **Verdrahtungsinduktivität klein halten:** kurze Wege zwischen Sicherung,
  Schalter und Last. Bei langen Batterieleitungen je Akku 220 µF/100 V direkt
  am Schalter-Eingang vorsehen (Abschalt-Spannungsspitzen!).
- Steuerteil: entweder auf Lochraster oder mit dem fertigen **Platinenlayout**
  [hardware/BatterySwitch_Steuerplatine.kicad_pcb](../hardware/BatterySwitch_Steuerplatine.kicad_pcb)
  (112×92 mm, 2 Lagen, Unterseite = GND-Zone — vor der Fertigung in KiCad
  öffnen, mit `B` die Zone füllen und den DRC laufen lassen). Anschluesse über
  Schraubklemmen: X4 = B1F/B2F/GND, X5 = Sense S1/S2, X6 = Gate/Source beider
  MOSFET-Paare, X7 = die beiden Frontplatten-Potis. Verbindungen
  zum Leistungsteil sind nur die zwei Gate/Source-Paare der VOM1271-Ausgänge
  und Masse. Die VOM1271-Ausgangsleitungen kurz halten und verdrillen.
- **Beide Sense-Abgriffe** (über F3/F4 100 mA) **direkt an der Anschlussklemme
  des jeweiligen Akku-Steckers** abnehmen, vor der Hauptsicherung F1/F2 – nicht
  irgendwo weiter hinten im Lastpfad. An die Batteriepole selbst muss (und kann)
  man bei Steckakkus nicht heran: Abfälle hinter dem Abgriff gehen nicht in die
  Messung ein, und der kleine Abfall über Akkukabel/Steckerkontakt (~0,1–0,3 V
  bei 40 A) wirkt nur wie etwas zusätzlicher Lasteinbruch. Damit der Fehler
  symmetrisch bleibt: **beide Akkuzuleitungen gleich ausführen** (Querschnitt,
  Länge, Steckertyp).
- **Gemeinsame Masse = nur im Umschalter-Kabelbaum:** Die Minus-Pins der
  beiden Akku-Stecker (X1, X2) werden im Kabelbaum direkt und niederohmig mit
  dem Fahrzeug-Minus (X3) verbunden. **An den Akkus selbst wird nichts
  geändert** – zieht man einen Akku ab und steckt ihn direkt ans Fahrzeug,
  fährt er wie gewohnt ohne Board. Die Verbindung ist nötig, weil der aktive
  Akku einen Stromrückweg braucht; für den inaktiven Akku ist sie unkritisch
  (Pluspfad beidseitig gesperrt, über Minus fließen nur ~1,3 mA Sense-Strom,
  keine Ausgleichsströme).
- **Betrieb mit nur einem Akku am Board** funktioniert ebenfalls: Der leere
  Steckplatz liest über den Messteiler 0 V, die Schaltung bleibt dauerhaft
  auf dem vorhandenen Akku.
- RV1/RV2 (Frontplatten-Potis) mit kurzen, verdrillten Leitungen anschließen –
  die Knoten sind hochohmig. Beide Messteiler (R1–R4) thermisch benachbart
  platzieren, damit Temperaturdrift gleichsinnig wirkt.

## 2. Erste Inbetriebnahme (Steuerteil, ohne Leistungspfad)

Für die ersten Tests genügt **ein** Akku oder ein Netzteil mit 58 … 72 V
(zur Not zwei 30-V-Labornetzteile in Serie). Strombegrenzung auf 100 mA.
Leistungs-MOSFETs noch nicht mit der Last verbinden.

1. Versorgung an BAT1+, beide Sense-Eingänge zunächst **zusammen** an dieselbe
   Quelle, GND anschließen.
2. **VCC prüfen:** ≈ 12 … 12,5 V. T5 darf nur mäßig warm werden.
3. **Inverter prüfen:** OUT und /OUT müssen komplementär sein
   (eine Status-LED an, eine aus).
4. **Gate-Treiber prüfen:** Am aktiven Zweig ≈ 8 V zwischen Gate und
   Source-Knoten, am inaktiven ≈ 0 V. Beim Umschalten muss das neue Gate
   sichtbar langsam kommen (einige ms, mit Oszi gut zu sehen), das alte
   schnell fallen.

## 3. Nullabgleich (RV3) – einmalig

Der Nullabgleich kompensiert die Toleranzen der Teilerwiderstände, damit
„U1 = U2“ auch wirklich als gleich erkannt wird. Bei der ÷28-Teilung erzeugen
schon 1-%-Widerstände bis ±1 V Scheindifferenz – dieser Schritt ist Pflicht.

**Variante A – mit Multimeter (empfohlen, keine 72-V-Quelle mit Feinregelung nötig):**

1. **JP1 und JP2 öffnen** (Δ-Einspeisungen getrennt).
2. Beide Sense-Eingänge zusammen an einen Akku (oder die Testquelle) klemmen.
3. Mit dem Multimeter Knoten A und Knoten B messen (≈ 2,1 … 2,6 V) und RV3 so
   einstellen, dass **beide Knoten auf < 1 mV gleich** sind (1 mV am Knoten
   ≈ 30 mV auf Batterieebene).
4. **JP1 und JP2 wieder schließen.**

**Variante B – über den Kipppunkt:** Wie A, aber mit fein einstellbarer Quelle:
RV3 auf die Mitte des Bereichs stellen, in dem die LEDs wechseln/flackern
(ohne Hysterese ist Flackern am Kipppunkt normal).

## 4. Einstellen von Δ1 und Δ2 (RV1/RV2)

Volle Präzision braucht zwei unabhängige 58…72-V-Quellen – die hat kaum jemand.
Praktikabel sind zwei Wege:

**Variante A – rechnerisch über die Knotenspannung (Multimeter genügt):**

1. Beide Sense-Eingänge zusammen an eine Quelle/einen Akku, Zustand
   „Akku 1 aktiv“ (LED1 an; ggf. durch kurzes Öffnen von JP2 erzwingen).
2. Knoten A messen, dann **JP1 öffnen** und erneut messen. Die Differenz ΔU(A),
   geteilt durch α = 0,0357, ist das aktuell eingestellte Δ1:
   `Δ1 ≈ ΔU(A) / 0,0357` (z. B. 36 mV Differenz ≙ 1,0 V). RV1 entsprechend
   einstellen, JP1 schließen. Für Δ2 analog mit JP2/Knoten B im Zustand
   „Akku 2 aktiv“.
3. Als Startwert taugt auch die Tabelle in der
   [Schaltungsbeschreibung](schaltung.md) (Poti-Stellung → Δ).

**Variante B – im Betrieb mit beiden Akkus:** Beide Akkus mit unterschiedlichem
Ladezustand anschließen, Last zuschalten und die Umschaltpunkte über die
Akkuspannungen (BMS-App/Voltmeter) beobachten; Potis nachführen.

**Wahl der Werte:**

- Δ1 **größer als der Lasteinbruch** des Akkus bei Volllast wählen. Bei 40 A an
  einem 72-V-Paket sind je nach Innenwiderstand 1 … 3 V Einbruch realistisch –
  im Zweifel Δ1 ≈ 1,5 … 2 V als Start.
- Δ2 etwa 0,3 … 0,5 V größer als Δ1, wenn selten zurückgeschaltet werden soll.
- **Wechselwirkung beachten:** Jedes Poti verschiebt das andere Δ um ca. 10–25 %
  (feste Zusatzhysterese). Beide Einstellungen 1–2× im Wechsel wiederholen.
- Pendelt die Schaltung unter Volllast (schnelles Hin- und Herschalten): beide
  Δ vergrößern, bis `Δ1 + Δ2 > 2 × Lasteinbruch`.

## 5. Test unter Last

1. Beide Akkus über die Sicherungen anschließen, zunächst **kleine Last**
   (z. B. Lampe/Widerstand, wenige A).
2. Umschalten provozieren: den aktiven Akku zusätzlich belasten (Spannung sackt
   ab) und beobachten, ob sauber auf den anderen Akku gewechselt wird – und erst
   nach deutlicher Erholung (Δ2) zurück.
3. Danach schrittweise bis zur Volllast (40 A) steigern und die
   **MOSFET-Temperatur überwachen**: Nach 30 min Dauerlast sollte der Kühlkörper
   handwarm bis warm (< 60 °C) sein. Wird er heißer: Kühlkörper vergrößern oder
   (falls noch nicht geschehen) zweites MOSFET-Paar je Zweig parallel bestücken.
4. Spannungsabfall über dem aktiven Schalter messen: bei 40 A und einem Paar
   ≈ 0,2 V, bei zwei parallelen Paaren ≈ 0,1 V. Deutlich mehr deutet auf
   schlechte Gate-Ansteuerung (VOM1271-LED-Strom prüfen: ~10 mA) oder
   Übergangswiderstände an den Klemmen hin.

## 6. Typische Probleme

| Symptom | Ursache | Abhilfe |
|---|---|---|
| Schaltet häufig hin und her | Δ1+Δ2 kleiner als 2× Lasteinbruch (inkl. Kabel/Stecker-Abfall); oder Sense-Abgriff hinter F1/F2 statt an der Steckerklemme | Potis Richtung mehr Δ; Sense-Abgriff direkt an die Anschlussklemme legen |
| Umschaltpunkte stimmen nicht / unsymmetrisch | Nullabgleich fehlt oder verstellt | Abschnitt 3 wiederholen |
| Δ ändert sich beim Drehen am anderen Poti | prinzipbedingt (feste Zusatzhysterese, 10–25 %) | wechselseitig nachjustieren |
| MOSFETs werden sofort heiß | UGS zu klein → nicht voll durchgesteuert | Gate-Source ≈ 8 V? VOM1271-LED-Strom ≈ 10 mA? T1/T2 schalten durch? |
| Keine Funktion, VCC = 0 | Zener/Regler-Pfad | ZD3-Spannung (13 V) und R19a/b prüfen |
| Beide LEDs glimmen / undefiniert | Störungen an den Messknoten, Masseschleife | C3/C4 bestückt? Steuerungs-Masse sternförmig anbinden |
| Last fällt beim Umschalten 5–10 ms aus | prinzipbedingt (Break-before-make) | unkritisch für Motorcontroller (eigene Zwischenkreis-Elkos); sonst C8 vergrößern |
| Beide Akkus tiefentladen | prinzipbedingt: nur Relativvergleich | BMS der Akkus ist letzte Instanz; ggf. externen Low-Voltage-Disconnect ergänzen |

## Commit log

2026-07-13 Batterieumschalter 12V/40A: Schaltungsdesign mit Poti-Hysterese
    Vollständiges Hardware-Design für die automatische Umschaltung zwischen
    zwei 12-V-Akkus (50Ah primär, 30Ah Reserve) anhand der Batteriespannung:
    - LM393-Komparator mit TL431-Referenz, Schwelle per Trimmer (7,4-14,6V)
    - Hysterese per Poti einstellbar (ca. 0,4-2,0V) über Mitkopplung
    - High-Side-Schalter aus antiseriellen IRLB3034-MOSFETs (40A Dauerstrom)
    - NE555-Ladungspumpe für die Gate-Versorgung
    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
2026-07-13 Umstellung auf Differenzvergleich der beiden Akkus mit zwei Potis
    Statt fester Umschaltschwelle (TL431-Referenz) werden die beiden
    Akkuspannungen jetzt direkt miteinander verglichen:
    - Umschalten auf Akku 2, wenn U1 < U2 - Delta1 (Poti 1, ca. 0,3-2,3V)
    - Zurueckschalten auf Akku 1, wenn U2 < U1 - Delta2 (Poti 2, unabhaengig)
    - Feste Zusatzhysterese (~0,1-0,5V je Richtung) gegen haeufiges Schalten
    Aenderungen im Detail:
    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
2026-07-13 Auslegung auf 72-V-System (58-72V) umgestellt
    Die Akkus haben ~71,x V Ladeschluss / ~58 V Entladeschluss - alle
    spannungsabhaengigen Teile neu dimensioniert:
    - MOSFETs: IRF100P219 (100 V, 2,4 mOhm) statt 40-V-Typen; Empfehlung
    zwei Paare parallel je Zweig (ca. 4,3 W statt 8,5 W bei 40 A)
    - Gate-Ansteuerung: Photovoltaik-Treiber VOM1271 statt NE555-Ladungs-
    pumpe (potentialfrei ueber der 72-V-Schiene, uA-Ladestrom liefert
    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
2026-07-13 KiCad-Schaltplan (72V/40A) plus Generator und SVG-Vorschau
    - hardware/BatterySwitch.kicad_sch: kompletter Schaltplan im KiCad-6-
    Format (lesbar mit KiCad 6/7/8/9), ein Blatt A3, alle Bloecke:
    Leistungspfad mit antiseriellen IRF100P219-Paaren, VOM1271-Gate-
    Treiber, 12-V-Hilfsspannungsregler, Messteiler mit Nullabgleich,
    LM393-Differenzkomparator mit den zwei Hysterese-Potis, Status-LEDs
    - hardware/tools/generate_schematic.py: Generator-Skript (Layout-
    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
    [BatterySwitch.kicad_sch]
2026-07-14 Sense-Abgriff an der Steckerklemme statt am Batteriepol dokumentiert
    Bei Steckakkus (Super Soco) ist der Batteriepol nicht zugaenglich. Der
    Sense-Abgriff erfolgt daher an der Anschlussklemme des Akku-Steckers im
    Umschalter, vor der Hauptsicherung F1/F2 - elektrisch unkritisch:
    - Abfaelle hinter dem Abgriff (F1/F2, MOSFETs) gehen nicht in die
    Messung ein (Sense-Zweig zieht nur ~1 mA)
    - Der Abfall ueber Akkukabel/Steckerkontakt (~0,1-0,3 V bei 40 A)
    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
    [BatterySwitch.kicad_sch]
2026-07-14 Bestellliste mit Haendlern, Links und ca.-Preisen; IRF100P219 ist TO-247
    - docs/bestellliste.md: Einkaufsliste nach Haendlern gruppiert
    (Mouser fuer MOSFETs/VOM1271, Reichelt fuer Standardbauteile,
    Solar-/PV-Quellen fuer gPV-Sicherungen, Grandado-Links des Nutzers
    fuer die Super-Soco-Stecker, Baumarkt fuer Kabel/Kleinteile) mit
    ca.-Preisen inkl. MwSt (Stand Juli 2026) und Gesamtuebersicht
    - Korrektur: IRF100P219 ist TO-247 (nicht TO-220) mit <= 2 mOhm laut
    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
2026-07-14 Platinenlayout fuer die Steuerplatine (KiCad-PCB, geroutet)
    - hardware/BatterySwitch_Steuerplatine.kicad_pcb: 112x92 mm, 2 Lagen,
    alle 38 Signalnetze fertig geroutet (423 Segmente, 12 Vias),
    GND als Flaechenzone auf der Unterseite, 4x M3-Montageloecher,
    Schraubklemmen fuer V+/Sense/Gates und die Frontplatten-Potis.
    Der 40-A-Leistungspfad bleibt bewusst ausserhalb der Platine
    (Chassis-Aufbau mit 10 mm2, siehe Aufbauanleitung).
    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
    [BatterySwitch_Steuerplatine.kicad_pcb]
2026-07-14 Klarstellung: gemeinsame Masse nur im Umschalter-Kabelbaum
    Die Minusleitungen der beiden Akku-Stecker werden ausschliesslich im
    Kabelbaum des Umschalters mit dem Fahrzeug-Minus verbunden - an den
    Akkus selbst wird nichts geaendert. Damit bleibt der Einzelbetrieb
    (ein Akku direkt am Fahrzeug, ohne Board) uneingeschraenkt moeglich.
    Ergaenzt: Betrieb mit nur einem Akku am Board funktioniert ebenfalls
    (leerer Steckplatz liest 0 V, Schaltung bleibt auf dem vorhandenen
    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
